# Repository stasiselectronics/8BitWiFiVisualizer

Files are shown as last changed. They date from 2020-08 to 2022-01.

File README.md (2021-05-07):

# 8 Bit WiFi Visualizer
Open Source Hardware project for a minimalist WiFi enabled 8 Bit visualizer. This design uses the popular ESP8266 wifi module to drive 8 LEDs with a shift register.
<h2><a href="https://stasiselectronics.github.io/8BitWiFiVisualizer/docs/">Check out the Docs!</a></h2>
<h2><a href="https://www.tindie.com/products/stasis/8-bit-wifi-visualizer/">Order on Tindie!</a></h2>

## Network Traffic Visualizer
Want to visualize how busy your WiFi channel is? The included Arduino sketch measures how many packets are flying around on the selected channel and displays the intensity on the LEDs.

With the help of some automated functions, the board selects the WiFi channel with the strongest network present at startup. It then automatically adjusts the display range to keep up with changing network conditions.

[Learn more about how this firmware works!](https://stasiselectronics.github.io/8BitWiFiVisualizer/docs/enclosure/automatic-firmware/)

<p align="center">
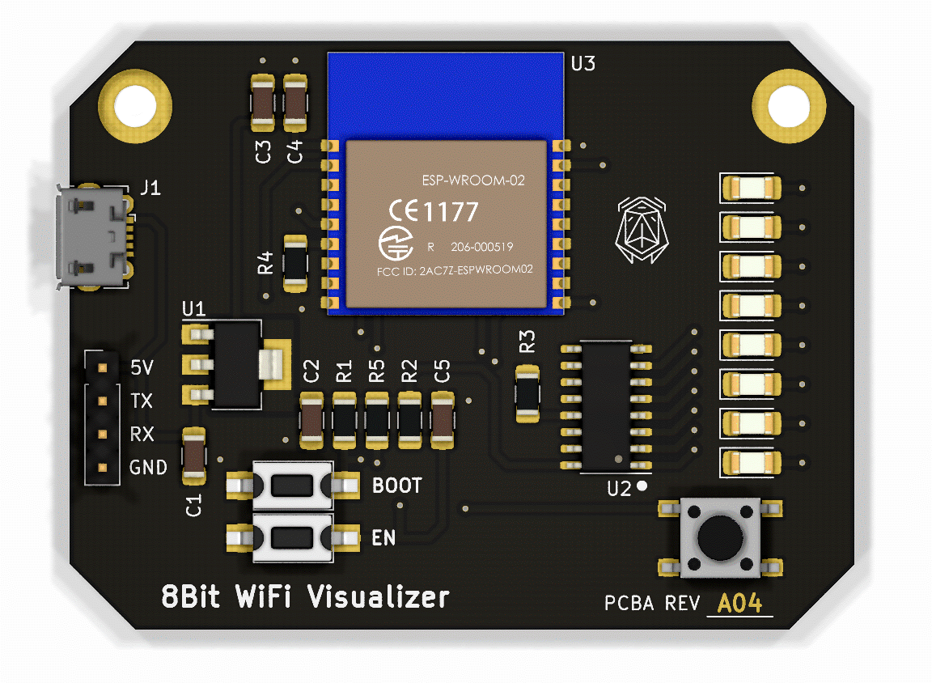
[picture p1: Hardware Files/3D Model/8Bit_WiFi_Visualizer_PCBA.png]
Render
  
</p>

<p align="center">
  
   
  
</p>
This repository contains all the source files needed to reproduce this project. The PCB is designed with KiCAD and the firmware uses Arduino for the ESP8266.

This is still a work in progress, so be sure to check back for future updates!

## Companion Site
I've put together a Github pages site to host all the documentation that goes with this design. Learn more about how everything works and keep up to date with blog posts. 

<h4>This is still a work in progress, more to come!</h4>

[Check out the companion site for more documentation!](https://stasiselectronics.github.io/8BitWiFiVisualizer/)

## Quick Links
- [Board Schematics](https://github.com/stasiselectronics/8BitWiFiVisualizer/blob/master/Hardware%20Files/PDFs/8Bit_WiFi_Visualizer_Schematic.pdf)
- [Arduino Sketch](https://github.com/stasiselectronics/8BitWiFiVisualizer/blob/master/Firmware%20Files/PacketVisualizer_auto/PacketVisualizer_auto.ino)

## Current Status

This project is nearing completion, here are some of the latest updates
- Redesigned PCB for larger components to make hand soldering easier
- Assembled and tested latest PCB design
- Major firmware updates
    - Auto selecting AP channel on startup
    - Auto ranging intensity scale with linear decay
    - Change AP channel with user button

## Future Goals

Here's what needs to get done for this project:
- Complete Documentation

Most of the project is now complete, so now all that is left is to finish up the documentation

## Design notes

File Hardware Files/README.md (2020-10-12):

# Hardware Files

Here you can find all the files for the PCB design. The board is designed in KiCAD

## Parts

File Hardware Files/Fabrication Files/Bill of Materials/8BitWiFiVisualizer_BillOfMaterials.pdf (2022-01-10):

## github.com/stasiselectronics tindie.com/stores/stasis/ @stasis.electronics

## Bill of Materials

01/10/2022

## 1 of 1

# Bill Of Materials

# PCBA Revision A05

Item Qty | Designator | Value

1 4

C1 C2 C4 C5 | 1uF | Samsung Electro-Mechanics | CL31B105KCHNNNE | C13832 | ☐

2 1

C3 | 10uF | Samsung Electro-Mechanics | CL31B106KAHNNNE | C14860 | ☐

3 8

D1 D2 D3 D4 D5 D6 D7 D8 | LED | Lite-On | LTST-C150TBKT | C125088 | ☐

4 1

J2 | Conn_01x04 | MINTRON | MTP125-1104S1 | C358686 | ☐

5 1

J1 | USB_B_Micro | Korean Hroparts Elec | U-F-M5DD-Y-L | C91146 | ☐

6 5

R1 R2 R3 R4 R5 | 10k | YAGEO | RC1206JR-0710KL | C136460 | ☐

7 1

SW1 | SW_Push_Dual | Hongyuan Precision | 1TS005F-2500-5001 | C255812 | ☐

8 2

SW2 SW3 | SW_SPST | Hongyuan Precision | 1TS002B-2700-5000-CT | C318844 | ☐

9 1

U1 | 3.3V 1A | Diodes Incorporated | AZ1117CH-3.3TRG1 | C92102 | ☐

10 1

U2 | 74HC595 | Nexperia | 74HC595D,118 | C5947 | ☐

11 1

U3 | ESP-WROOM-02D | Espressif Systems | ESP-WROOM-02D | C473007 | ☐

# 8 Bit WiFi Visualizer

Part 1
MF

Part 1
MPN

Part 1
Ordering Code

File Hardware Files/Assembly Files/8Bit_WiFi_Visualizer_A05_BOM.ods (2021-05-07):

8 Bit WiFi Visualizer
Item | Qty | Designator | Value | Part 1 MF | Part 1 MPN
1 | 4 | C1 C2 C4 C5 | 1µF 10% 100V | Samsung Electro-Mechanics | CL31B105KCHNNNE | 𝥷
2 | 1 | C3 | 10µF 10% 25V | Samsung Electro-Mechanics | CL31B106KAHNNNE | 𝥷
3 | 8 | D1 .. D8 | Blue LED | Lite-On | LTST-C150TBKT | 𝥷
4 | 1 | J2 | 1x4 2.54mm Header | MINTRON | MTP125-1104S1 | 𝥷
5 | 1 | J1 | Micro USB Connector | Korean Hroparts Elec | U-F-M5DD-Y-L | 𝥷
6 | 5 | R1 R2 R3 R4 R5 | 1206 10K 5% 0.25W | YAGEO | RC1206JR-0710KL | 𝥷
7 | 1 | SW1 | SW_SPST 6mmx6mm | Hongyuan Precision | 1TS005F-2500-5001 | 𝥷
8 | 2 | SW2 SW3 | SW_SPST 6mmx3.5mm | Hongyuan Precision | 1TS002B-2700-5000-CT | 𝥷
9 | 1 | U1 | 15V 3.3V 1.3V @ 800mA | Diodes Incorporated | AZ1117CH-3.3TRG1 | 𝥷
10 | 1 | U2 | 74HC595 Shift Register | Nexperia | 74HC595D,118 | 𝥷
11 | 1 | U3 | ESP WROOM Module | Espressif Systems | ESP-WROOM-02D | 𝥷

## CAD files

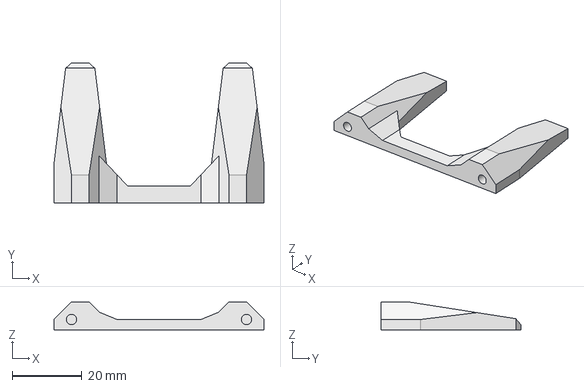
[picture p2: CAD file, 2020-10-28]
3D Printed Files/8BitWiFiVisualizer_stand.FCStd
60.0 x 40.0 x 8.00 mm

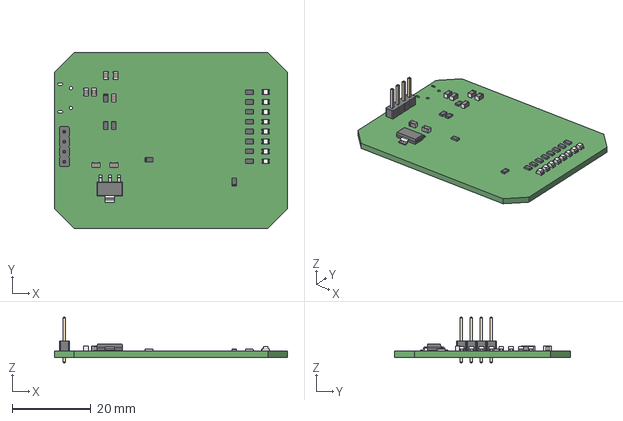
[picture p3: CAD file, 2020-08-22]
Hardware Files/3D Model/8Bit_WiFi_Visualizer_PCBA.step
59.0 x 44.5 x 11.5 mm

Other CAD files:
3D Printed Files/8BitWiFiVisualizer_stand.stl

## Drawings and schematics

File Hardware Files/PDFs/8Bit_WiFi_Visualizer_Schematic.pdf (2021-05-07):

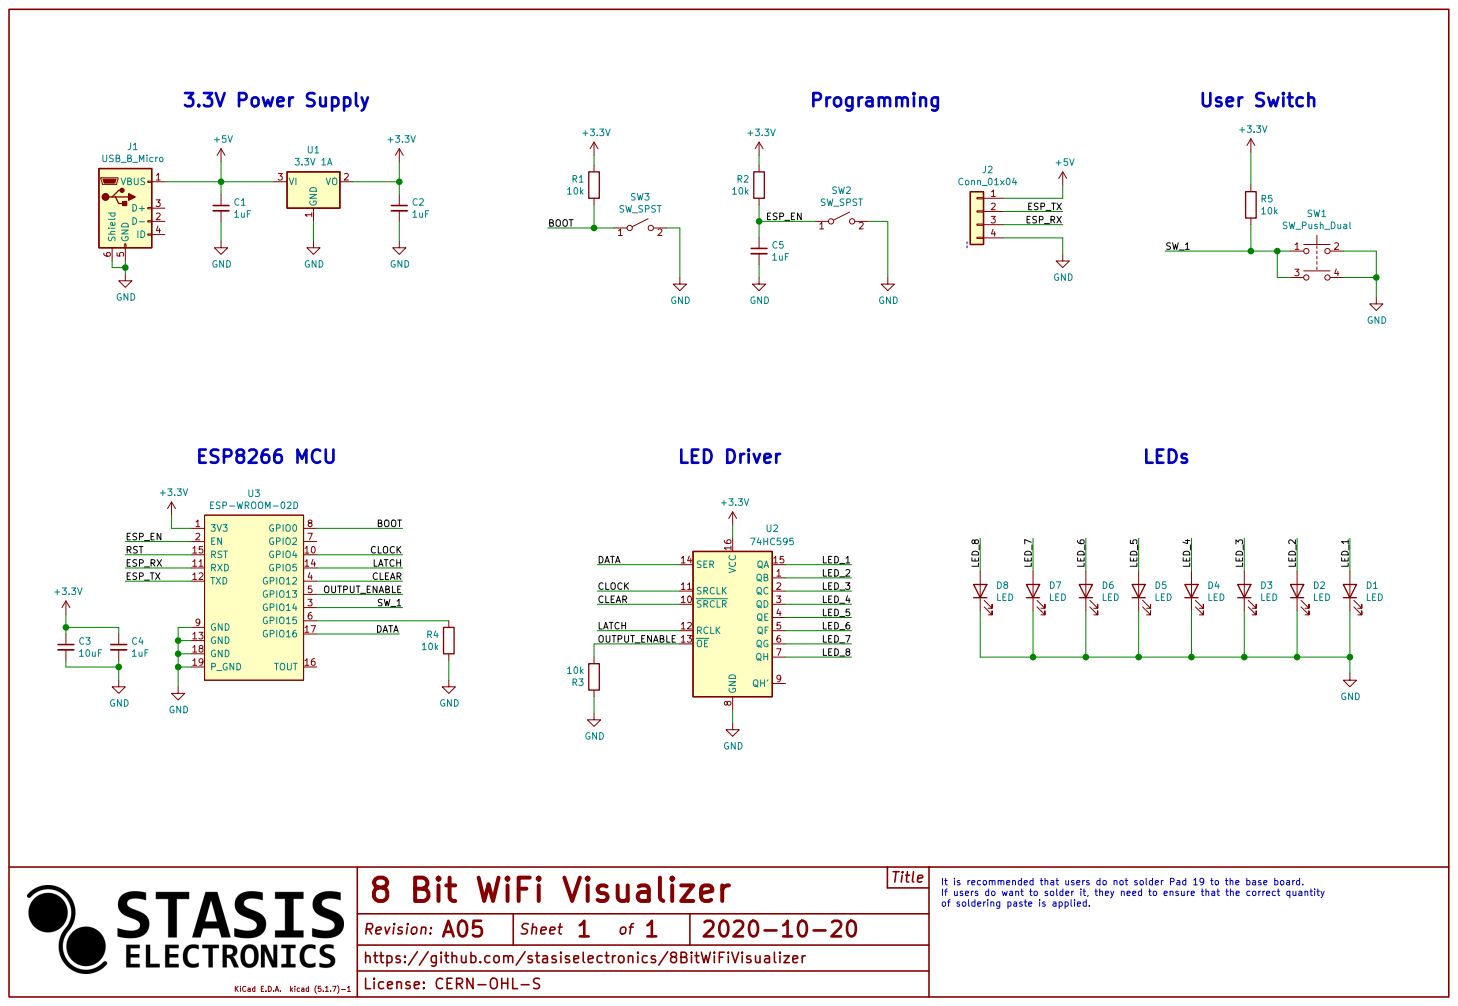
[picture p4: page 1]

https://github.com/stasiselectronics/8BitWiFiVisualizer GND

Title 8 Bit WiFi Visualizer

It is recommended that users do not solder Pad 19 to the base board.
If users do want to solder it, they need to ensure that the correct quantity
of soldering paste is applied.

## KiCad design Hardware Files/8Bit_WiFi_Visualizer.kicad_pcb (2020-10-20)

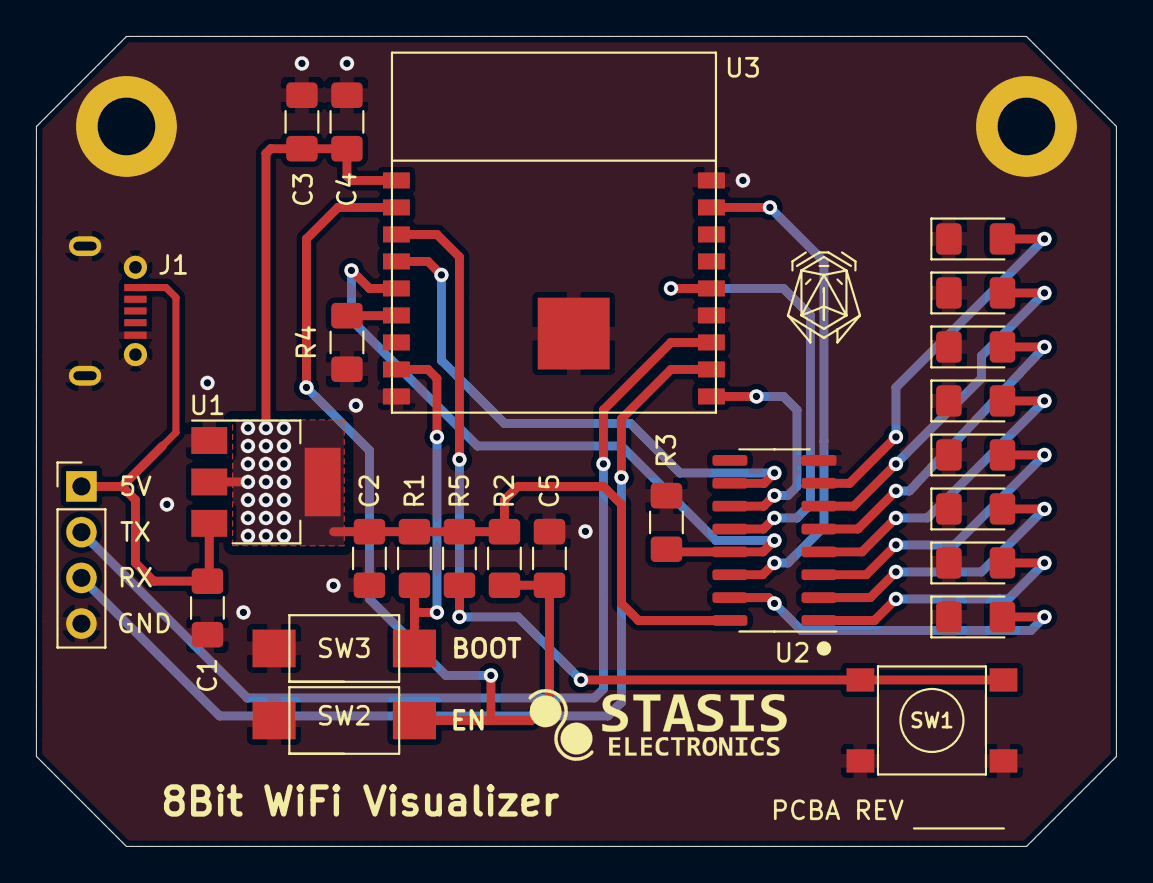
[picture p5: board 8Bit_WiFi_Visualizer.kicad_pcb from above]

Board: 2 copper layers, 60.0 x 45.0 mm, 28 parts (0 on the bottom side), 22 nets.

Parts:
C1, C2, C4, C5: 1uF; C_1206_3216Metric_Pad1.42x1.75mm_HandSolder
C3: 10uF; C_1206_3216Metric_Pad1.42x1.75mm_HandSolder
D1, D2, D3, D4, D5, D6, D7, D8: LED; LED_1206_3216Metric_Pad1.42x1.75mm_HandSolder
J1: USB_B_Micro; U-F-M5DD-Y-L
J2: Conn_01x04; PinHeader_1x04_P2.54mm_Vertical
J3, J4: Conn_01x01; MountingHole_3.2mm_M3_DIN965_Pad
R1, R2, R3, R4, R5: 10k; R_1206_3216Metric_Pad1.42x1.75mm_HandSolder
SW1: SW_Push_Dual; PTS645SK50SMTR92LFS
SW2, SW3: SW_SPST; PTS636_SM25F_SMTR_LFS
U1: 3.3V 1A; SOT-223-3_TabPin2
U2: 74HC595; SOIC-16_3.9x9.9mm_P1.27mm
U3: ESP-WROOM-02D

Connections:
+3V3: C2.1, C3.1, C4.1, R1.1, R2.1, R5.1, U1.2, U2.16, U3.1
+5V: C1.1, J1.1, J2.1, U1.3
/BOOT: R1.2, SW3.1, U3.8
/CLEAR: U2.10, U3.4
/CLOCK: U2.11, U3.10
/DATA: U2.14, U3.17
/ESP_EN: C5.1, R2.2, SW2.1, U3.2
/ESP_RX: J2.3, U3.11
/ESP_TX: J2.2, U3.12
/LATCH: U2.12, U3.14
/LED_1: D1.2, U2.15
/LED_2: D2.2, U2.1
/LED_3: D3.2, U2.2
/LED_4: D4.2, U2.3
/LED_5: D5.2, U2.4
/LED_6: D6.2, U2.5
/LED_7: D7.2, U2.6
/LED_8: D8.2, U2.7
/OUTPUT_ENABLE: R3.2, U2.13, U3.5
/SW_1: R5.2, SW1.1, SW1.3, U3.3
GND: C1.2, C2.2, C3.2, C4.2, C5.2, D1.1, D2.1, D3.1, D4.1, D5.1, D6.1, D7.1, D8.1, J1.5, J1.6, J2.4, J3.1, J4.1, R3.1, R4.2, SW1.2, SW1.4, SW2.2, SW3.2, U1.1, U2.8, U3.9, U3.13, U3.18, U3.19
unnamed: R4.1, U3.6

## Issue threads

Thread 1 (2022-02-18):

i have a little question

MRHERT, 2022-02-18:
can we use a signal 2.4GHZ amplifier for the esp8266 in order to increase the range oF IT ?

ChandlerMcCowan, 2022-02-18:
Unfortunately I don't think so. The ESP8266 has a PCB trace antenna. That means the antenna (and the RF Signals transmitted and received) are being routed through a specially designed copper trace on the module itself.

[View more about trace antennas ](https://en.wikipedia.org/wiki/Microstrip_antenna)

to externally amplify the signal would also risk entering into the territory of improperly operating radio equipment, which depending on where you are might be more off limits than others.

To even access the RF signals would mean accessing that trace antenna and attempting to solder onto a connector. There are a few ESP modules that have a u.fl connector. That would make it much easier to access the RF signals, but I don't think it would work since the RF communication is bi-directional (transmitting and receiving).

I believe the ESP8266 has options in firmware to adjust the transmitting power. But to increase it's reception is really to increase the transmitting power of the signals you are looking for. Otherwise you would be improving the ability for the device to pick up and understand weaker signals, something I don't think is worth trying to make happen with an ESP8266.

Let me know if you have other questions, happy to help.

I will close this issue, but don't hesitate to open a new one!

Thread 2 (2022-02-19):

wemos d1 mini

MRHERT, 2022-02-19:
thank you for you responding  for example lets take wemos d1 mini as an example i use it as access point but the signal is not strong as router it can go just throw a single wall how can we make that signal powerful is it possible do you have any suggestions please ?
thank you

ChandlerMcCowan, 2022-02-23:
a WiFi Radio has to conform to certain standards, so it can be difficult to extend the  transmission power of compliant devices.

[A quick search found this article](https://wlan1nde.wordpress.com/2014/11/26/wlan-maximum-transmission-power-etsi/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,(63%20mW)%20for%20CCK.)

Think about the application and what the solution needs to solve the problem. Is WiFi the right type of radio to use, or could you experiment with other technologies to solve the problem?

Closed 2022-02-23.

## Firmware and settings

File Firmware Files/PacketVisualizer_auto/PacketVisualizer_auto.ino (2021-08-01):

// Chandler McCowan
// Network Traffic Indicator using ESP8266 and 8 LEDs
// Advanced Firmware Version
// This firmware is intended for the Stasis Electronics 8 Bit WiFi Visualizer board

// Use this firmware if you want more advanced features such as:
//  - Auto scan available networks to select channel with strongest network
//  - Auto range the packets per second to automatically configure the max rate
//  - Change LED brightness to match packet rate intensity
//  - Filter for smoother LED changes
//  - Change AP Channel with user button

// AP Channel: This is the network channel that the visualizer listens to, it only looks at one channel at a time.
//             This firmware will automatically look for the channel with the strongest wifi network

  int ap_channel = 1; // This will be changed automatically on setup
  
// Max Rate: This is the maximum rate of packets per seconds that will be displayed, and will then be divided by 8 to determine
//           This firmware will automatically adjust this value as it runs

  double max_rate = 100; // packets per second // This will be changed automatically as the device runs

// Refresh Rate: This is how often the display is updated, and is used in calculating the packets per second.

  int refresh_rate = 100; // ms // Feel free to change!

// LED Brightness: You can use the PWM functionality on the Output Enable pin to set a brightness for the LEDs.
//                 Use a value between 0 and 1023, where 1023 is "off", and 950 is "dim" and 0 is fully "on"
//                 This firmware allows you to specify a brightness for every displayed value, growing in brightness as
//                 packet rate intensifies. Array begins with value 1, and goes to value 8

  int led_brightness[8] = {1020, 1010, 1000, 950, 900, 500, 300, 0};


// Header files to include
#include <ESP8266WiFi.h>
#include <EEPROM.h>

// GPIO Pin Definitions
// Changing these will affect the board's functionality, do so at your own risk!
#define LATCH 5 
#define CLOCK 4  
#define DATA 16   
#define SWITCH 14
#define CLEAR 12
#define OUTPUTENABLE 13

// variable that is incremented everytime a packet is sniffed
unsigned volatile long pkts = 0;

// Call Back function to capture packets and increment variable
void counter() {
  pkts++;
}


void setup() {
  Serial.begin(115200);                // begin Serial port and set the baud rate to 115200, feel free to change this if you want
  Serial.print("\n\n\n");              // helps to clear the application dialogue and the ESP8266's boot dialogue
  Serial.println("Auto Selecting Channel");

  // Arduino ESP8266 Core 3.0.2 changed the AnalogWrite range from 12 bit to 8 bit
  // The new ranges are from 0-255 instead of 0-1023
  // Page 15 of the release documentation offers the following function to fix this without changing
  // the values in the application
  analogWriteRange(1023);
    
  // GPIO Port Configuration
  Serial.println("Initializing Pins");
  pinMode(LATCH, OUTPUT);
  pinMode(CLOCK, OUTPUT);
  pinMode(DATA, OUTPUT);
  pinMode(CLEAR, OUTPUT);
  pinMode(OUTPUTENABLE, OUTPUT);
  pinMode(SWITCH, INPUT);               
  
  // Set initial pin conditions
  digitalWrite(CLEAR, HIGH);                      // Active Low
  analogWrite(OUTPUTENABLE, 1010);                // Active Low

  digitalWrite(LATCH, LOW);
  shiftOut(DATA, CLOCK, MSBFIRST, 255);
  digitalWrite(LATCH, HIGH);

  // Auto Select Channel
  ap_channel = get_channel();
  if(ap_channel<1||ap_channel>11){
    ap_channel=1;
    Serial.println("AP Channel out of bounds, set ap_channel to something between 1 and 14");
  }

  // Display which channel was selected
  digitalWrite(LATCH, LOW);
  shiftOut(DATA, CLOCK, MSBFIRST, ap_channel);
  digitalWrite(LATCH, HIGH);
  for(int i = 0; i < 4; i ++){
    digitalWrite(OUTPUTENABLE, HIGH);
    delay(300);
    analogWrite(OUTPUTENABLE, 500);
    delay(300);
  }
  
  // Networking Setup, sets ESP8266 into Promiscuous mode and adds the packet counter function to the call back
  Serial.print("Initializing Network Settings on Channel ");Serial.println(ap_channel);
  wifi_set_opmode(STATION_MODE);                                // Promiscuous works only with station mode
  wifi_set_channel(ap_channel);                                 // Set which channel we are listening to
  wifi_promiscuous_enable(0);                                   // make sure promiscuous mode is disabled so we can add our call back function
  wifi_set_promiscuous_rx_cb((wifi_promiscuous_cb_t)counter);   // Set up promiscuous callback. Typecasted to match expected pointer type
  wifi_promiscuous_enable(1);                                   // enable promisuous mode with our new call back function
  Serial.println("Network Settings Configured");
  
  Serial.println("Finished Setup, Starting loop");
}

void loop() {
  static unsigned long prevTime = 0;       // timer variable to use to see if enough time has passed since last display update
                                           // "static" means the compiler won't re-initialize the variable every loop
  static byte previous_value = 0;          // value used to make sure we only update the display as needed
  static double filtered_rate = 0;         // variable to hold a filtered version of the packets per second
  static unsigned int button_timer = 0;    // variable to keep track of how long the button has been presed
  static unsigned int debounce_timer = 0;  // variable to keep track of any debouncing when pressing the button
  static bool change_channel_flag = false; // Flag to ignore button press if we just changed the channel

  ESP.wdtFeed();  // Feed watchdog timer just in case, since we are doing nothing most of the time
  
  if(millis() - prevTime >= refresh_rate) // check if it is time to update the display
  {
    prevTime = millis();                  // update timer variable for next display update

    double packets_per_second = (pkts*(1000/refresh_rate)); // calculate how many packets per second have occured since last display
                                                            // 1000 is used to convert milliseconds to seconds

    if(packets_per_second>filtered_rate){
      filtered_rate = packets_per_second;                   // Ignore filter if change is positive
    }
    else{
      filtered_rate -= filtered_rate*((double)refresh_rate/1000)*2;   // fall back the displayed value in a half second
      if(filtered_rate<0){
        filtered_rate=0;
      }
    }
    
    
    pkts = 0;                             // reset packets counter variable for next calculation

    if(packets_per_second>max_rate){
      max_rate = filtered_rate;           // auto adjust max rate
    }
    else if(max_rate < 100){
      max_rate = 100;                     // set minimum max rate
    }
    else {
      max_rate-= 1;                       // have max rate fall back over time
    }
    
    byte led_value = pow(2,ceil((filtered_rate/max_rate)*8.0)) - 1;
    //Serial.println(ceil((filtered_rate/max_rate)*8.0));

    
    
    if(previous_value!=led_value){
      // Display Value
      digitalWrite(LATCH, LOW);
      shiftOut(DATA, CLOCK, MSBFIRST, led_value);
      digitalWrite(LATCH, HIGH);
      previous_value=led_value;
      analogWrite(OUTPUTENABLE, led_brightness[(byte)ceil((filtered_rate/max_rate)*8.0)-1]);      // Set LED Brightness
    }
    
    // Print to terminal, if refresh rate is too fast, you might find some errors in writing out to serial
    // Serial.print("Packet Rate: "); Serial.print(packets_per_second); Serial.println(" packets per second");
    // Serial.print(packets_per_second);Serial.print(",");Serial.print(filtered_rate);Serial.print(",");Serial.println(max_rate); // some more debug outputS
  }

  // check button state and perform debouncing
  if(!digitalRead(SWITCH)){
    if(button_timer==0 && !change_channel_flag){
      button_timer = millis();              // button is first pressed, start a timer to see how long it has been pressed
    }
    else{
      if(button_timer !=0 && millis() - button_timer>2000){     // long press has occured, allow to change channel
        button_timer = 0;
        debounce_timer = 0;
        change_channel();
        change_channel_flag = true;
      }
    }
  }
  else{// button is not pressed, so lets check if it has been recently pressed to apply debounce
    change_channel_flag = false;
    if(button_timer > 0 && debounce_timer == 0){
      debounce_timer = millis();            // button was just released, start a timer to check if it is just debouncing
    }
    else if(button_timer > 0 && debounce_timer > 20){
      debounce_timer = 0;
      button_timer = 0;
    }
    if(button_timer > 0 && millis() - button_timer > 100){
      // this would be a short press
      max_rate = 100; // reset max range
      button_timer = 0;
      debounce_timer = 0;
    }
  }
}

int get_channel(){
  // function looks at all available networks and returns the channel that has the strongest network present
  int wifi_networks_n = 0;    // Number of wifi networks present, and used to reference details of the networks
  int max_rssi = -1000;       // RSSIs are negative, so initialize to something below any actual network strength
  int strongest_network = 0;  // Number in list of wifi networks, used to print for reference
  
  WiFi.mode(WIFI_STA);        // Make sure ESP8266 is in station mode
  WiFi.disconnect();          // Make sure we're not connected to any network
  wifi_networks_n = WiFi.scanNetworks();  // Get number of available networks, used to access array of wifi networks

  if(wifi_networks_n == 0){
    Serial.println("No Networks Found, that's not right, who doesn't have a WiFi network around?");
    return 0;
  }
  else{
    for (int i = 0; i < wifi_networks_n; ++i) {
      // look through wifi networks and find strongest network strength and save corresponding network channel
      if(WiFi.RSSI(i)>max_rssi){
        strongest_network = i;
        max_rssi=WiFi.RSSI(i);
      }
    }
    Serial.print("Found strongest network ");Serial.print(WiFi.SSID(strongest_network));
    Serial.print(" with RSSI of "); Serial.print(WiFi.RSSI(strongest_network));
    Serial.print(" on channel ");Serial.println(WiFi.channel(strongest_network));
    return(WiFi.channel(strongest_network));
  }
}

void change_channel(){
  bool done_flag = false;
  unsigned long timer1 = millis();
  unsigned long button_timer = 0;
  unsigned long debounce_timer = 0;
  Serial.println("Changing Channel");
  digitalWrite(OUTPUTENABLE, LOW);
  digitalWrite(LATCH, LOW);
  shiftOut(DATA, CLOCK, MSBFIRST, ap_channel);
  digitalWrite(LATCH, HIGH);
  while(!digitalRead(SWITCH)){
    // button is still being depresed, wait until released
    ESP.wdtFeed();
    if(millis()-timer1 >= 500){
      timer1 = millis();
      //toggle LEDs
      digitalWrite(OUTPUTENABLE, !digitalRead(OUTPUTENABLE));
    }
  }
  while(!done_flag){
    ESP.wdtFeed();
    if(millis()-timer1 >= 500){
      timer1 = millis();
      //toggle LEDs
      digitalWrite(OUTPUTENABLE, !digitalRead(OUTPUTENABLE));
    }
    if(!digitalRead(SWITCH)){
    if(button_timer==0){
      button_timer = millis();
    }
    else{
      if(millis() - button_timer>2000){
        // long press condition
        button_timer = 0;
        done_flag = true;
        }
      }
    }
    else{
      if(button_timer > 0 && debounce_timer == 0){
        debounce_timer = millis();
      }
      else if(button_timer > 0 && millis() - debounce_timer > 20){
        debounce_timer = 0;
        button_timer = 0;
      }
      if(button_timer > 0 && millis() - button_timer > 100){
        // this would be a short press
        ap_channel++;
        if(ap_channel>11){
          ap_channel = 1;           // wrap around back to channel 1
        }
        digitalWrite(LATCH, LOW);
        shiftOut(DATA, CLOCK, MSBFIRST, ap_channel);
        digitalWrite(LATCH, HIGH);
        button_timer = 0;
        debounce_timer = 0;
      }
    }
    
  }
  Serial.print("Setting Channel to ");Serial.println(ap_channel);
  wifi_set_channel(ap_channel); 
}

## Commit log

2019-11-25 Update Silkscreen
    [PacketVis.kicad_pcb]
2020-03-02 Update SCH to A4 page size
    [BOM.xlsx, PacketVis.sch]
2020-03-02 Update Routing
    [PacketVis.kicad_pcb]
2020-03-10 Add 5V to Programming Header
    [PacketVis.kicad_pcb, PacketVis.sch]
2020-08-22 Changed U2 to 5v TTL Shift Register needs 5V instead of previous 3.3V Traces rerouted Added PCBA Step File
    [PacketVis.kicad_pcb, PacketVis.sch, PacketVis_PCBA.step]
2020-08-22 Added Schematic PDF
2020-08-22 Updated Gerbers and Drills
    [PacketVis-B_Cu.gbr, PacketVis-B_Mask.gbr, PacketVis-B_Paste.gbr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]
2020-08-23 Fixed Missing REFS on PCB
    [PacketVis-B_Cu.gbr, PacketVis-B_Mask.gbr, PacketVis-B_Paste.gbr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]
2020-08-23 Fixed FAB Files
    [PacketVis-B_Cu.gbr, PacketVis-B_Mask.gbr, PacketVis-B_SilkS.gbr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]
2020-09-11 move 3D PCBA model
    [PacketVis_PCBA.step]
2020-09-11 Move Schematic PDF
2020-09-11 Move Fabrication Files
    [PacketVis-B_Cu.gbr, PacketVis-B_Mask.gbr, PacketVis-B_SilkS.gbr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]
2020-09-11 update fabrication file output location
    [PacketVis.kicad_pcb]
2020-09-11 upate BOM generation
    [PacketVis.sch]
2020-09-26 Change Shift Register back to 3.3V
    [PacketVis-B_Cu.gbr, PacketVis-B_Mask.gbr, PacketVis-B_SilkS.gbr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]
2020-09-28 Move Files into Hardware Folder
    [PacketVis-B_Cu.gbr, PacketVis-B_Mask.gbr, PacketVis-B_SilkS.gbr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]
2020-09-28 Change LEDs to source current from shift register, unroute most tracks
    [PacketVis.kicad_pcb, PacketVis.sch]
2020-09-29 Rename Project Files
    [8Bit_WiFi_Visualizer.kicad_pcb, 8Bit_WiFi_Visualizer.sch]
2020-09-29 Update Schematic Libraries
    [8Bit_WiFi_Visualizer.sch]
2020-09-29 Update Footprint Libraries
    [8Bit_WiFi_Visualizer.sch]
2020-09-29 Update Project Title
    [8Bit_WiFi_Visualizer.sch]
2020-09-29 Add 3D model to ESP02 footprint
2020-09-29 Update esp02 model on board
    [8Bit_WiFi_Visualizer.kicad_pcb]
2020-09-29 add custom molex footprint with 3d model
2020-09-29 Update microusb to include 3D model
    [8Bit_WiFi_Visualizer.kicad_pcb, 8Bit_WiFi_Visualizer.sch]
2020-09-29 Update SPST switch footprint to include 3D Model
    [8Bit_WiFi_Visualizer.kicad_pcb]
2020-09-29 Update tactile switch footprint to include 3D model
    [8Bit_WiFi_Visualizer.kicad_pcb, 8Bit_WiFi_Visualizer.sch]
2020-09-29 update PCBA 3D Model
    [8Bit_WiFi_Visualizer_PCBA.step]
2020-09-29 Add silkscreen layer
2020-09-29 Update Project Revision
    [8Bit_WiFi_Visualizer.sch]
2020-09-29 Cleanup Schematic
    [8Bit_WiFi_Visualizer.sch]
2020-09-29 Change to 1206 components and reroute
    [8Bit_WiFi_Visualizer.kicad_pcb, 8Bit_WiFi_Visualizer.sch]
2020-09-29 change components to 1206 footprints and remove some components
    [8Bit_WiFi_Visualizer.sch]
2020-09-30 Update Logo
    [8Bit_WiFi_Visualizer.kicad_pcb]
2020-10-01 Reposition Reference Designators
    [8Bit_WiFi_Visualizer.kicad_pcb]
2020-10-01 Re-Annotate Schematic
    [8Bit_WiFi_Visualizer.sch]
2020-10-01 Re-Annotate PCB
    [8Bit_WiFi_Visualizer.kicad_pcb]
2020-10-01 Add missing logo
    [8Bit_WiFi_Visualizer.kicad_pcb]
2020-10-01 Rename and Update Schematic
2020-10-01 Update Gerbers
    [8Bit_WiFi_Visualizer-B_Cu.gbr, 8Bit_WiFi_Visualizer-B_Mask.gbr, 8Bit_WiFi_Visualizer-B_SilkS.gbr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]
2020-10-01 Lock Logo to prevent deletion on update from schematic
    [8Bit_WiFi_Visualizer.kicad_pcb]
2020-10-02 Scrub BOM details
    [8Bit_WiFi_Visualizer.sch]
2020-10-02 Add descriptions
    [8Bit_WiFi_Visualizer.sch]
2020-10-02 update part numbers
    [8Bit_WiFi_Visualizer.sch]
2020-10-02 fix USB MPN
    [8Bit_WiFi_Visualizer.sch]
2020-10-12 Add Stand Files
    [stand-withslot.FCStd, stand-withslot.stl]
2020-10-15 Update pin mapping for A04
2020-10-15 add cut to nubs (are they really called nubs?)
    [stand-withslot.FCStd, stand-withslot.stl]
2020-10-17 Add button functions and autoscan RSSI
2020-10-17 Fix up basic firmware
    [PacketVisualizer_basic.ino]
2020-10-18 Add low pass filter
2020-10-18 change filtering type
2020-10-18 add button functionality
2020-10-19 Change capacitors to 1uF
    [8Bit_WiFi_Visualizer.sch]
2020-10-19 Change USB connector and update revision
    [8BitWiFiVisualizer_BOM.xlsx, 8Bit_WiFi_Visualizer.kicad_pcb, 8Bit_WiFi_Visualizer.sch]
2020-10-19 Update part numbers and silkscreen
    [8BitWiFiVisualizer_BOM.xlsx, 8Bit_WiFi_Visualizer.kicad_pcb]
2020-10-19 Update Gerbers for A05
    [8Bit_WiFi_Visualizer-B_Cu.gbr, 8Bit_WiFi_Visualizer-B_Mask.gbr, 8Bit_WiFi_Visualizer-B_SilkS.gbr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]
2020-10-19 add gerbers
2020-10-19 Updates for A05
    [8Bit_WiFi_Visualizer.kicad_pcb]
2020-10-20 Move Logo and update GERBERS
    [8Bit_WiFi_Visualizer-B_Cu.gbr, 8Bit_WiFi_Visualizer-B_Mask.gbr, 8Bit_WiFi_Visualizer-B_SilkS.gbr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]
2020-10-22 rearrange Schematic
    [8Bit_WiFi_Visualizer.sch]
2020-10-28 add new stand design
    [8BitWiFiVisualizer_stand.FCStd, 8BitWiFiVisualizer_stand.stl]
2020-10-28 remove old stand files
    [stand-withslot.FCStd, stand-withslot.stl]
2020-11-11 Update Title Block
    [8Bit_WiFi_Visualizer.sch]
2021-05-07 add BOM from microBBPS to use as a template
    [8BitWiFiVisualizer_A05_BOM.ods]
2021-05-07 update content to A05 board parts
    [8BitWiFiVisualizer_A05_BOM.ods]
2021-08-01 Add fix for AnalogWrite() range from 3.0.2 Arduino ESP8266 Core
    [PacketVisualizer_auto.ino]
2022-01-10 add new BOM
    [8BitWiFiVisualizer.ods]
2022-01-10 update content of BOM
    [8BitWiFiVisualizer.ods]
2022-01-10 update name
    [8BitWiFiVisualizer_BillOfMaterials.ods]
2022-01-10 add export of Bill of Materials
